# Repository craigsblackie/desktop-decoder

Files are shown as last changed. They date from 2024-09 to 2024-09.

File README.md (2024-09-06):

# Desktop Wiegand Decoder

Overview
--------

Useful tool to easily display an encoded hex value of the Wiegand data transmitted over the wire from an Access Control reader.
Aimed as a visual aid for confirming effective credential clones, and technology downgrade attacks.
Also capable of easily retrieving PACS data from "secure" credentials making use of default encryptions keys, such as HID SEOS.

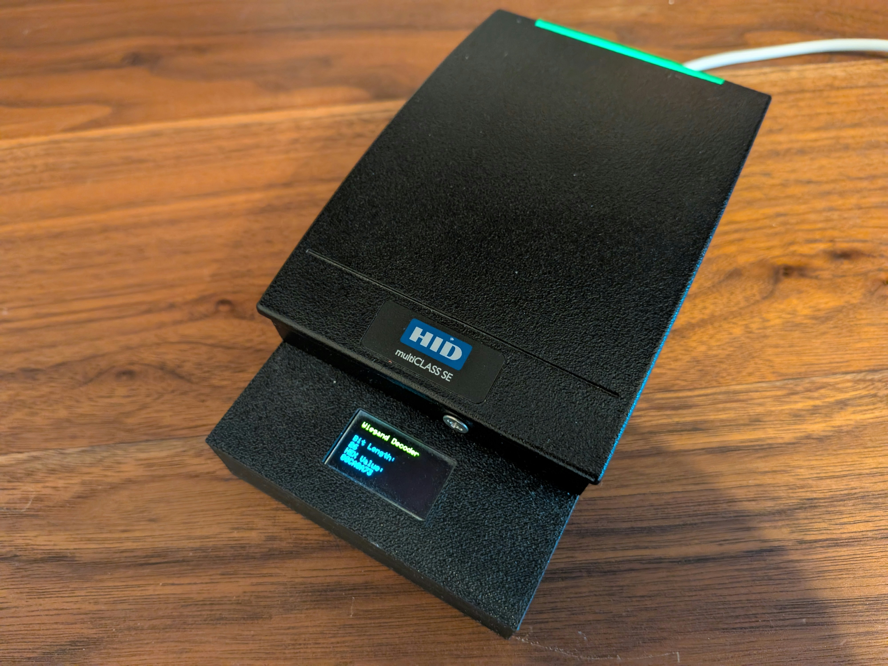
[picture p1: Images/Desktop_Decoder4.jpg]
HIDRP40


Kit List
--------

*   Wiegand Based reader
    *   HID RP40 or RPK40 Multiclass SE is the best as it has the ability to read both low frequency as well as high frequency cards
*   Arduino Nano
*   Arduino OLED screen
    *   [OLED Screen](https://www.amazon.co.uk/gp/product/B08NDJ3S3Q/ref=ppx_yo_dt_b_asin_title_o02_s00?ie=UTF8&psc=1)
* USB-C PD board
    * Fun fact. HID RPK40s boot on 5v, so no need to buy a big USB-C PD compatible power supply if you dont want.

Build Instructions
------------------

### Pinout

The pinout is from the perspective of all components to avoid mistakes and aid in troubleshooting.

#### Reader

*   Wiegand Data 1 - D3 (Arduino)
*   Wiegand Data 0 - D2 (Arduino)
*   +12v - +12v (USB PD Board)
*   Gnd - Gnd (USB PD Board)

#### Arduino

*   VIN - +12v (USB PD Board)
*   GND - Gnd (USB PD Board)
*   D2 - Wiegand Data 0 (Reader)
*   D3 - Wiegand Data 1 (Reader)
*   A4 - SDA (OLED)
*   A5 - SCL (OLED)
*   5v - VCC (OLED)
*   GND - Gnd (OLED)

#### OLED

*   SDA - A4 (Arduino)
*   SCL - A5 (Arduino)
*   VCC - 5v (Arduino)
*   Gnd - GND (Arduino)

### Case

If you have access to a 3D printer, this STL prints quickly and doesnt require any supports. It also has slots for each peice of hardware.
Case secured making use of M3 bolts, which thread into the PLA plastic to avoid the need for brass thread inserts.
Reader fixed to case using M3 bolts as well.

*   [USB C PD Board](https://www.amazon.co.uk/Youmile-charge-trigger-module-voltage/dp/B09WTQC5Q4)
*   [Bolt pack](https://www.amazon.co.uk/TOOINKCV-Metric-Washers-Assortment-Machine/dp/B0CLRRKVV6)

### Optional Wifi addon

Added functionality can be had with an RFID-Tool installed into the same case to add the ability to retrieve the data read via Wi-Fi. This tool connects in-line with the reader, and doesn't interfere with the arduino.

*   [RFID-Tool](https://labs.ksec.co.uk/product/esp-rfid-tool/)

Usage
-----

As simple as it gets: turn it on and scan any card that the connected reader is capable of reading. PACS data and bit length will be displayed on the screen. This data can be written to another card using a Proxmark or similar device, decoded to retrieve the facility code and card number.

This serves as a visual aid for effective card cloning and tech downgrade attacks to confirm that PACS data is transmitted identically.

HIDRPK40

### Credits
* Craig S. Blackie and Warren Houghton

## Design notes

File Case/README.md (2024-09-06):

# 3D printed case

Case designed for use with a larger HID Multiclass reader, such as the RP40 or RPK40.
Sections to hold the different components in the case, with a drop of super glue

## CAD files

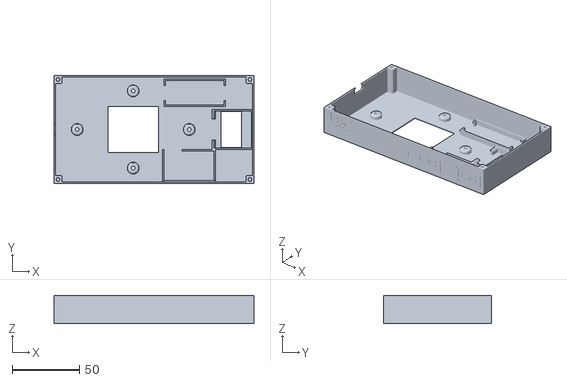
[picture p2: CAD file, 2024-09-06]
Case/Case.stl
148.3 x 80.2 x 21.0

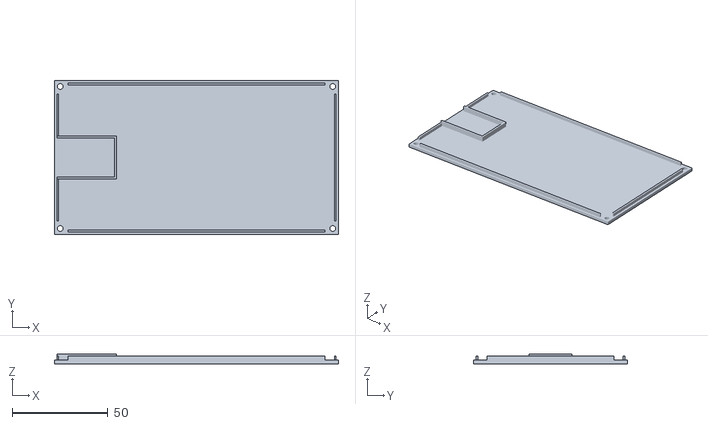
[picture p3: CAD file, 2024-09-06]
Case/Lid.stl
148.4 x 80.2 x 5.00

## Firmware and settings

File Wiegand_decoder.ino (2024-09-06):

#include <Wire.h>
#include <Wiegand.h>
#include <Adafruit_GFX.h>
#include <Adafruit_SSD1306.h>

// These are the pins connected to the Wiegand D0 and D1 signals.
// Ensure your board supports external Interruptions on these pins
#define PIN_D0 2
#define PIN_D1 3

#define SCREEN_WIDTH 128 // OLED display width, in pixels
#define SCREEN_HEIGHT 64 // OLED display height, in pixels

// The object that handles the wiegand protocol
Wiegand wiegand;

String numCard = "";

// Declaration for an SSD1306 display connected to I2C (SDA, SCL pins)
Adafruit_SSD1306 display(SCREEN_WIDTH, SCREEN_HEIGHT, &Wire, -1);

void setup() {
  Serial.begin(115200);
  display.begin(SSD1306_SWITCHCAPVCC, 0x3C);
  // Show initial display buffer contents on the screen --  
  display.clearDisplay();
  display.setTextSize(1);
  display.setTextColor(WHITE);
  // Booting Reader Screen
  display.setCursor(00,00);
  //display.display();
  display.println("   Reader Booting");
  display.display();
  delay(9000);
  display.clearDisplay();
   //Install listeners and initialize Wiegand reader
  wiegand.onReceive(receivedData, "Card read: ");
  wiegand.onReceiveError(receivedDataError, "Card read error: ");
  wiegand.begin(Wiegand::LENGTH_ANY, false);
  
  //initialize pins as INPUT and attaches interruptions
  pinMode(PIN_D0, INPUT);
  pinMode(PIN_D1, INPUT);
  attachInterrupt(digitalPinToInterrupt(PIN_D0), pinStateChanged, CHANGE);
  attachInterrupt(digitalPinToInterrupt(PIN_D1), pinStateChanged, CHANGE);

  //Sends the initial pin state to the Wiegand library
  pinStateChanged();

}

// When any of the pins have changed, update the state of the wiegand library
void pinStateChanged() {
  wiegand.setPin0State(digitalRead(PIN_D0));
  wiegand.setPin1State(digitalRead(PIN_D1));
}

// Notifies when a card was read.
// Instead of a message, the seconds parameter can be anything you want -- Whatever you specify on `wiegand.onReceive()`
void receivedData(uint8_t* data, uint8_t bits, const char* message) {
    //Serial.print(message);
    Serial.print(bits);
    Serial.print("bits / ");
    display.clearDisplay();
    display.setCursor(00,50);
    //Print value in HEX
    uint8_t bytes = (bits+7)/8;
    for (int i=0; i<bytes; i++) {
        Serial.print(data[i] >> 4, 16);
        Serial.print(data[i] & 0xF, 16);
        display.print(data[i] >> 4, 16);
        display.print(data[i] & 0xF, 16);
    }
    display.setCursor(00,30);
    //Print number of bits
    display.print(bits);
    Serial.println();
}

// Notifies when an invalid transmission is detected
void receivedDataError(Wiegand::DataError error, uint8_t* rawData, uint8_t rawBits, const char* message) {
    //Serial.print(message);
    //Serial.print(Wiegand::DataErrorStr(error));
    Serial.print(" Raw data: ");
    Serial.print(rawBits);
    Serial.print("bits / ");
    display.clearDisplay();
    display.setCursor(00,50);
    //Print value in HEX
    uint8_t bytes = (rawBits+7)/8;
    for (int i=0; i<bytes; i++) {
        Serial.print(rawData[i] >> 4, 16);
        Serial.print(rawData[i] & 0xF, 16);
        display.print(rawData[i] >> 4, 16);
        display.print(rawData[i] & 0xF, 16);
    }
    display.setCursor(00,30);
    //Print number of bits
    display.print(rawBits);
    Serial.println();
}

void outputOLED(String displayMessage){
// Display static text
    display.println(displayMessage);
}

void titleBar() {
// Title bar disaplay
  display.setCursor(00,00);
  //display.display();
  display.println("Wiegand Decoder");
  display.display();
}

// Every few milliseconds, check for pending messages on the wiegand reader
// This executes with interruptions disabled, since the Wiegand library is not thread-safe
void loop() {
  noInterrupts();
  wiegand.flush();
  interrupts();
  //Sleep a little -- this doesn't have to run very often.
  delay(100);
  titleBar();
  display.setCursor(0,20);
  //display.display();
  outputOLED("Bit Length:");
  display.setCursor(0,40);
  display.display();
  outputOLED("HEX Value:");
}
